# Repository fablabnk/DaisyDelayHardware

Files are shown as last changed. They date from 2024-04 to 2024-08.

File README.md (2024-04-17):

This repo documents the hardware design of a Daisy Seed-based Eurorack module called the Daisy Delay and contains the KiCad files for the project.

The Daisy Delay is planned as simple 6HP mono delay-line module, but can easily be used as a development platform for any kind of single-in/single-out audio processor.

This README gives an overview of the project, but there are also seperate notes for the [schematic](notes_schematic.md) and the [PCB](notes_pcb.md).

The module was first prototyped in VCVRack, before before being converted back to code that will run on the Seed. For more details on the VCVRack plugin, see [here](https://github.com/fablabnk/VaseProtoPlugin/tree/delay_line_params).

# Components / Bill of Materials (BOM)

The 

- 2 x 10K (for now) potentiometers
- 1 x SPST mini switch
- 1 x small LED (? diameter)
- 4 x Thonkiconn mono switching jack sockets (PJ301M-12)
- 1 x TL072 op amp
- 1 x TL074 op amp
- 1 x Shrouded 10 pin power connector
- various resistors
- various ceramic capacitors

# Workflow

Below is the basic workflow I am following to develop the module. 

1. Design schematic
- symbol and footprint for Seed Rev4 are already included in KiCad - search for "electrosmith"

2. Design front panel in Kicad PCB editor
- use VCV plugin panel .svg as template
- laser cut on paper / thin card first to test fit

3. Layout and Route PCB
- one board which drops onto components
- laser cut on paper / thin card first to test fit
- 2 layer / 4 layer routing?

4. Convert code to seed format
- test code on Pod

5. Send for fabrication (PCBWay)
- Order 5 x front and back panels

# Useful Links

https://github.com/clacktronics/Eurorack_KiCAD_templates

# Concerns / To Do

- Simpler hardware module first...probably!
- Symbol is only for Seed Rev 4 and we are now on Rev 7, but each Daisy Seed is pin to pin compatible with one another 
- Revisions were only to replace depricated audio codecs. See here: https://daisy.nyc3.cdn.digitaloceanspaces.com/products/seed/Daisy_Seed_datasheet.pdf

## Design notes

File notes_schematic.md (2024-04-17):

To put together the schematic for the Daisy Delay, I studied the schematics of the [Daisy Patch](https://daisy.nyc3.cdn.digitaloceanspaces.com/products/patch/ES_Daisy_Patch_Rev4.pdf) which contains most of what we need to know.

https://daisy.nyc3.cdn.digitaloceanspaces.com/products/patch-sm/ES_Daisy_Patch_SM_Schematic.pdf

# Switch and LED

The [datasheet PDF](https://daisy.nyc3.cdn.digitaloceanspaces.com/products/seed/Daisy_Seed_datasheet.pdf) has some

GPIO

`Pin Functions - Table 2`

# Eurorack 'conditioning'
There are three

1. ADC Inputs

2. Audio I/O
- attentuating a Eurorack level audio signal to line level on the way in
- boosts the line level signal to Eurorack level on the way out

3. Power
- deriving an isolated +5V from the Eurorack +-12V rails

# 1. ADC Inputs

For each of the two parameters in our Daisy Delay ('delay time' and 'feedback'), we need to:
    a. Sum the CV input voltage (coming in at the jack) with that of the potentiometer
    b. Scale the summed signal so that it falls within the range the Seed ADC pins expect (0-3.3V)

Here is the schematic for the circuit:

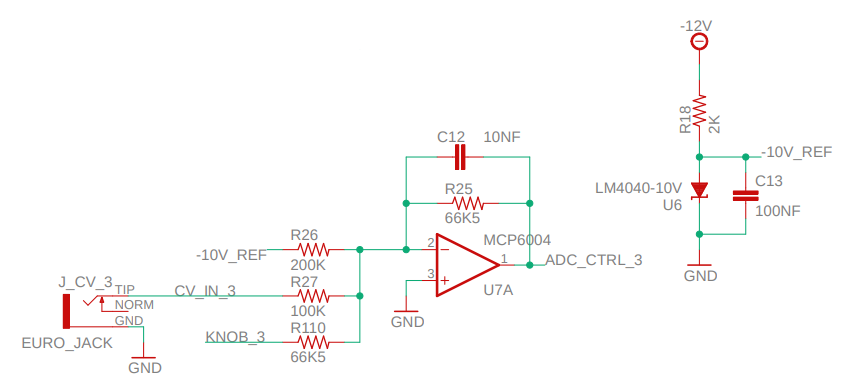
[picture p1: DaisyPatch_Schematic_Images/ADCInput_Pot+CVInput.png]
Pot + CV Input


## The Input Signals

Let's start with the CV input voltage (CV_IN_3). According to Eurorack standards this will fall within the +-5V range. It is followed by a 100K resistor.

Now let's consider the potentiometer (KNOB_3). We can see from another part of the schematic (below) that KNOB_3 is:
- a 10K potentimeter
- one side is connected to the `3.3V Analog` output pin of the Daisy Seed
- the other side is connected to ground
- the middle 'wiper' terminal comes into our circuit above

Connected in this way, the potentiometer creates a voltage divider circuit, where at one extreme of it's range, the output voltage on the wiper terminal will be close to 0V and at the other extreme it will be close to 3.3V. The chosen resistance value (in this case 10K) will affect the range, sensitivity, and resolution of the output voltage.

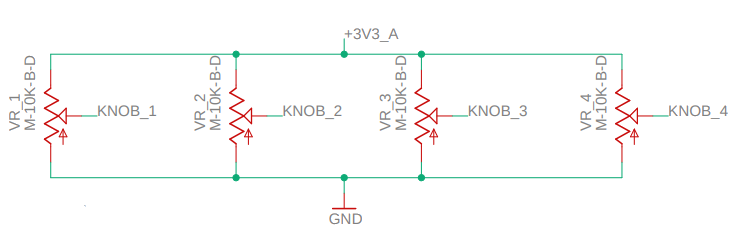
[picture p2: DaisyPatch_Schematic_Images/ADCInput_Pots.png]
Pots


So our KNOB_3 signal will fall within the 0-3.3V range. We can also see that it is followed by a 66.5K resistor.

Finally we have our -10V reference. On the right side of the first image above, we can see another schematic. This shows:
- our -12V coming in (from the Eurorack -12V rail)
- a 200K resistor placed in series with it
- then we [LM4040 Shunt Voltage Reference](https://www.ti.com/lit/ds/symlink/lm4040.pdf) whose purpose is to provide a stable and precise -10V output
- this is placed in parallel with a 100NF capacitor, to ensure a clean and stable output voltage under varying operating conditions
- both of which are connected to ground

Back on the left side, we can see that our -10V reference voltage is followed by a 200K resistor

## The Op Amp

We can see that our op amp is connected as follows:
- The negative input (known as the inverting input) is connected in parallel to a 10NF capacitor and a 66.5K resistor
    - These two components are also also both connected to the output of the op amp
    - This is also the output of our circuit (ADC_CTRL_3), which is connected to a Daisy Seed ADC Input pin
- The positive input (known as the non-inverting input) is connected to ground.

As we can see in the extra part of the schematic below, the op amp is powered by the same Daisy Seed pin that powers our potentiometers (the 3.3V Analog pin).

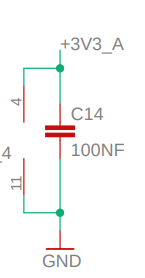
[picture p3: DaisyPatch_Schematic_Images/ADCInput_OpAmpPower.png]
Op Amp Power


This is an integrator circuit

`
The inverting amplifier can be extended by adding more input sockets (J1) and corresponding input resistors (R1). The right terminals of all input resistors are connected to the inverting input (-) of the operational amplifier O1. The relation between the corresponding input resistor R1 and R2 (the same for all inputs) defines the sensitivity of the input in question. If all resistors have the same value (e.g. 100 kOhm) the amplification is "1" for all inputs. Lowering R1 (e.g. 47k or 22k) increases the sensitivity of the input in question. Increasing R2 (e.g. 220k or 1M) increases the amplification resp. sensitivity for all inputs simultaneously.
`

weighted summing amplifier

[https://www.doepfer.de/DIY/a100_diy.htm]

Q: will the signal be "uninverted" in code 

We can note that:
-10V reference 200K
+-5V CV input 100K
0-3.3V potentiometer 66.5K
right side 66.5K

Q: what is the purpose of the -10V reference voltage? the -10V reference biases or shifts the level downwards

# 2. Audio I/O

Here we are using op amps again - in this case quad op amps in the form of the TL074. Let's begin this time by seeing how they are powered:

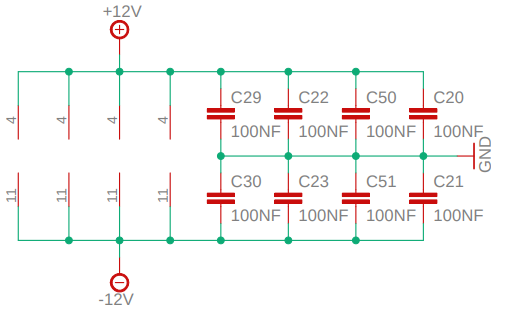
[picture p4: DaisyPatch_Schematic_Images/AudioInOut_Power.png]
Audio InOut Power


Here we can see that the op amp chips are powered directly from the eurorack +12V and -12V rails. For each quad op amp we use two 100NF capacitors to bridge across the + and - terminals to ground. This is to remove noise and/or smooth out any fluctuations in power.

Now let's look at our Audio In and Audio Out circuits next to each other:

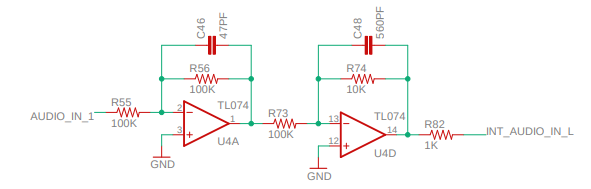
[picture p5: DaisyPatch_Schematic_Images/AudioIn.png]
Audio In

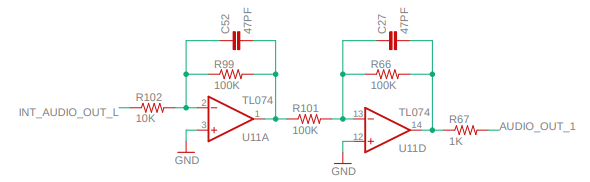
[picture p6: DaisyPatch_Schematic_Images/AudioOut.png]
Audio Out


Comparing them, we can see that:
- all the op amps are configured to operate as 'inverting' op amps i.e. the polarity between input and output is reversed
- both have a 1K resistor as the last element in the chain
- both have two op amp 'stages', including one with no amplification or attenution (100K resistor on left and right)
    - this is used to counteract the 'inverting' nature of the other op amp in the circuit
- the audio in circuit attenuates using the 2nd op amp (by having a 100K resistor on left, 10K resistor on right)
- the audio out circuit amplifies using the 1st op amp (by having a 10K resistor on left, 100K resistor on right)

Questions:
- Why always a 1K resistor at the end? Does the load have to be less?
- Why use inverting amplifiers at all?
- Why are TL074's used here with audio and MCP6004's when working with ADCs? They are both quad op amps. Answerish here: https://modwiggler.com/forum/viewtopic.php?t=193048

# 3. Power

We need +5V to power our Daisy Seed, the question is where it get it from? There are two options here:
1. Use the dedicated +5V rail (if we have it, most but not all power supplies do)
2. Derive our +5V from the +12V rail (e.g. with a regulator)

Commercial designs follow the second option to ensure ultimate compatability, but we don't have that concern (yet). The question is more, do all the power supplies we are likely to use have the +5V rail? The answer luckily is yes, in our case:
- the [TipTop µZeus](https://schneidersladen.de/de/tiptop-audio-uzeus-modul-mit-flying-bus-boards) does
- so too does our [USB Powerthingies](https://docs.google.com/document/d/1JAcD3iRaLf3Jpy0aVLl79c0GiPyVQEmC2FkkPij2Vjg/edit) by [Timo Rozendal](https://www.timorozendal.nl/)

Another aspect to take into account is that we need to use the larger 16-pin eurorack power connector when connecting our modules, which will take up more space on the PCB and will require a corresponding cable (do we have one?). Previously I have used the [eurocad](https://github.com/nebs/eurocad) library which contains a schematic component for a Eurorack 2x5 pin power header. Unfortunately, it did not contain one for the 2x8 pin version, so I decided to make my own, following the pinouts shown here:

Euro Power Connector Pinouts

To do this I used KiCad's symbol editor, found my EURO_PWR_2x5 symbol, right clicked it and chose `Derive from Existing Symbol`, then expanded the box size and copied in 6 more pins. In producing the symbol, I noticed two issues with the 

1. the pins for the EURO_PWR_2x5 did not correspond to the ones on the above diagram
    - for example pins 1 and 2 referenced the +12V rail not -12V!
    - this isn't an issue as long as I am shrouding the right way around in the footprint i.e.

Typically in Eurorack the we have a red stripe that represents the -12V rail and we use a shrouded connector to ensure the cable isn't inserted the wrong way around.

https://noiseengineering.us/blogs/loquelic-literitas-the-blog/how-to-plug-in-a-module

2. I also saw that all pins were marked 'power output' and have adapted my version to differentiate between 'power input' and 'power output' pins. My finished 16-pin connector symbol looks like this:

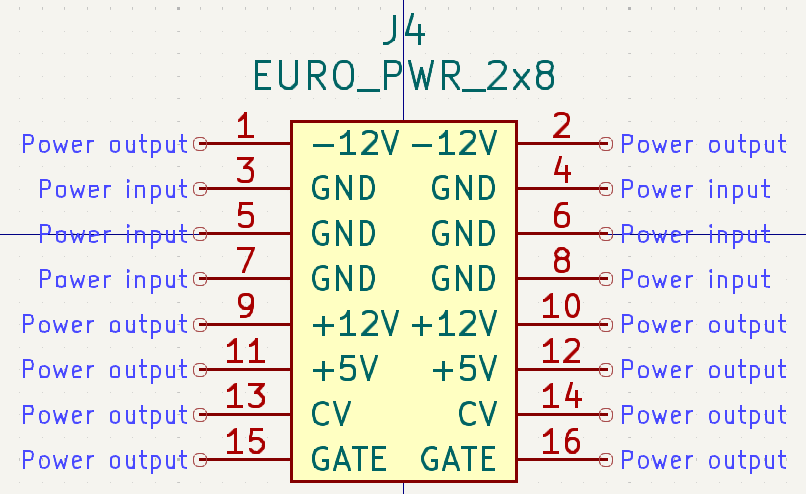
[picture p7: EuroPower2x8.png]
Euro Power 2x8 pin connector


## Deriving +5V from the +12v rail

If we did want to convert from +12V to +5V, we can look at how it was done in the Daisy Patch:

https://forum.kicad.info/t/please-explain-electrical-type-when-create-new-ic-pin/742/3

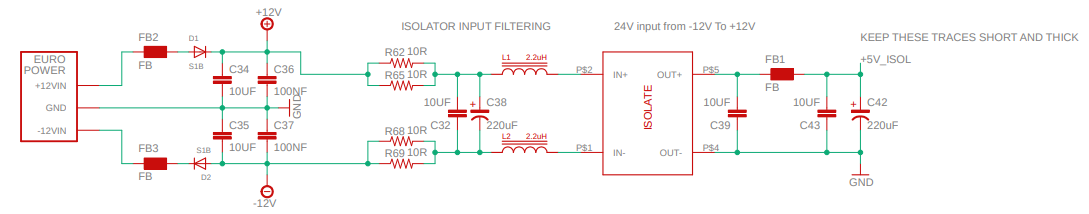
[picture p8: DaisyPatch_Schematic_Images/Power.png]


- The hoopy schematic symbols with two horizontal lines on top are iron core inductors
- The biggest point of confusion is the red 'isolate' box. What it is?

## Other power considerations

### Seed AGND to DGND

Note: For all applications, AGND must be connected to DGND!

### Capacitors

We can bridge capacitors from the power rails to ground, to help smooth out voltage fluctutions, maintain stability and eliminate interference. This is still a bit mysterious to me, but I did the following:

- For the +12V and -12V rails I placed 10uF and 100nF capacitors in parallel between the rail and ground, just as in the Daisy Patch power schematic above
- For the +5V rail I wasn't sure what is best practice, but again took from the above schematic after the 5V has been isolated, by placing 10uF (ceramic) and 220uF (electolytic) capacitors in parallel between the 5V rail and ground

### Ferrite beads

Supress high frequency noise
Should i use them?

# Things I learned along the way:

- how to protect the module from overvoltage and inserting the 10-pin cable the wrong way around (reverse polarity protection). Q: how is overvoltage handled actually?

- how to power the daisy seed using Eurorack +-12V by converting it to +-5V

- how small value capacitors are used between +12V and -12V and GND at each stage of our circuit to reduce noise e.g.
    - directly as the +-12V comes in from our Eurorack power supply
    - again when the +12V is used at the ADC Input stage
    - again when the +12V and +3.3V_A is used at our Audio In/Out stage
    - ???Why is a capacitor placed in parallel with resistor over input/output of op amp?

- how to convert from the signal levels Eurorack modules expect to ones that the Daisy Seed expects

- how to use an analog circuit sum the potentiometer value with the CV input value for each parameter

- which values potentiometers to use? i.e. does it matter if we use 10K, 50K, 100K?

# Elements of the Schematic

## Daisy Seed

The pins on the Daisy Seed we will need are as follows:

| Pin Name | Purpose |
| --- | --- |
| AUDIO_IN_L | Line-level audio input
| AUDIO_OUT_L  | Line-level audio output
| ADC_0 | Analog to Digital convertor pin for our 'Delay Time' potentiometer + CV Input
| ADC_1 | Analog to Digital convertor pin for our 'Feedback' potentiometer + CV Input
| ADC_2 | Analog to Digital convertor pin for our 'Delay Length Short/Long' switch
| DAC? | LED
| V_IN | Voltage input which we will feed with 5V (apparently 12V also okay but generate more heat)
| +3V3_A | 3.3V Analog power, feeding our potentiometers
| +3V3_D | Digital
| AGND | Analog ground
| DGND | Digital ground

Note: “D” for Digital GPIO or “A” for Analog I/O, depending on use case
Note: DGND and AGND must be connected to each other outside of the Seed.

Conveniently, a schematic symbol is already included in KiCad for the Daisy Seed Rev 4. We are now on Rev 7, but newer Daisy Seed revisions are pin to pin compatible with the old ones and were only made in order to replace unavailable audio codecs. See [here](https://daisy.nyc3.cdn.digitaloceanspaces.com/products/seed/Daisy_Seed_datasheet.pdf) for more details.

## Audio In/Out

We need to translate here from standard eurorack voltage levels (10V peak-to-peak) to line level (1-1.75Vpp) that the Daisy Seed audio input expects. We also need to do the opposite when the audio leaves the daisy seed. In practice we will use op amps to attenuate the signal coming in and boost it going out. Here we will use the same TL074 quad op amp chip as in the Daisy Seed, as each circuit requires two op amp stages (why?).

1. Audio In
- attentuates from Eurorack level to line level
- 100K resistor -> TL074 op amp 100K -> 100K resistor -> TL074 op amp 10K -> 1K resistor

2. Audio Out
- boosts from Eurorack level to line level
- 10K resistor -> TL074 op amp 100K -> 100K resistor -> TL074 op amp 100K -> 1K resistor

Note: I considered to share a 6 input op amp chip with our ADC Input section, but this cannot easily be done in practice as the former needs +-3.3V whilst this one needs +-12V

## Switch

- ADC is overkill here, GPIO makes more sense as our switch only has 0 (LOW) and 1 (HIGH) positions

- refer to the GPIO the example [here](https://electro-smith.github.io/libDaisy/md_doc_2md_2__a1___getting-_started-_g_p_i_o.html):

- use GPIO pin D0 (Daisy Seed pin 1)
- configured as an input
- configured use a pull up resistor
- my_button.Init(D0, GPIO::Mode::INPUT, GPIO::Pull::PULLUP);
- [Switch class](https://electro-smith.github.io/libDaisy/classdaisy_1_1_switch.html#ad14a8ae20033d940d6c9eeb03c138)void daisy::Switch::Init(dsy_gpio_pin pin,float update_rate, Type t, Polarity pol, Pull pu) 
- hardware: connect one side of the switch to the GPIO input, and other side to GND

## LED

- use GPIO pin D1 (Daisy Seed pin 2)
- configured as an output
- pull up/down is not relevant here
- We connect one side of our LED to the GPIO input and the other side to GND and use a pull up resistor?
- my_led.Init(D1, GPIO::Mode::OUTPUT);
- [LED class](https://electro-smith.github.io/libDaisy/classdaisy_1_1_led.html)void daisy::Led::Init(dsy_gpio_pin pin, bool invert, float samplerate = 1000.0f)	
- hardware: D0 -> resistor -> + LED - -> GND

Determine the forward voltage drop and current rating of the LED you intend to use. This information is crucial for selecting an appropriate resistor to limit the current through the LED. using  Ohm's Law.

## Power

The power circuit of the Daisy Seed details some 

1. We take +-12V from our Eurorack power supply using a 10-pin connector

2. For both the +12V and -12V rails, we insert separately:
    - a ferrite bead (to filter out very high frequency interference) [see here](https://modwiggler.com/forum/viewtopic.php?t=91515&start=10) apparently important for CPU-based module
    - an S1B diode (for reverse polarity protection). This not the only approach e.g. 1N4001 diodes

3. We bridge both rails to GND using 10uF and 100nF capacitors

- this is for noise reduction

4. We send out to our internal +-12V rails

5. Providing 5V to power the Seed

- we perform isolator input filtering
- we somehow drop the signal to 5V before sending to +5V_ISOL to power the seed (VIN)
- Q: What does the Isolate block do here?

Apparently another approach would be to step down using a LM7805 

# Which symbols and footprint to use for Thonkiconn jacks

symbol: Connector:AudioJack2_SwitchT
footprint: Connector_Audio:Jack_3.5mm_QingPu_WQP-PJ398SM_Vertical_CircularHoles

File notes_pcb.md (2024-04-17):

Q's?
- should LM4040 pin 3 be connected anywhere?
- what package should LM4040 have - what can we buy?
- what to do about switch - cut holes for it?
- panel layout
- don't forget thicker trace for power

# The process

- In schematic editor `Tools -> Edit Symbol Fields` helps to quickly and systematically assign footprints!
- Do we have a footprint for 2x8 Eurorack power connector? If not, make one!
    - closest generic is: Connector_PinHeader_2.54mm:PinHeader_2x08_P2.54mm_Vertical - using it for now
    - also could use the one from HagiwoMixer
- Need to order the following physical components
    - MCP6002
    - LM4040-10 - which package - SOT-23 or 

- LED diameter - 3mm/5mm? Note: Resistor value is dependent on desired brightness and/or LED part
- switch dimensions
- switch is not PCB mountable - what to do here? where to place on board, which footprint to use?
- breadboard the switch and LED as an example
- this time do a design rules check

# Multiple boards
The design will require two stacked PCBs

1. Mounting board
    - for pots, jacks etc
2. Seed board
    - for

- Components will be mounted onto the front side of board 1
- The panel will sit on top and be attached by thonkiconn screws
- On the rear side of board 1 there will be pin sockets to the left and right
- On the front side of board 2 there will be pin headers
- How many pins will be needed?
- On the rear side of board 2 there will left and right pin headers for the daisy seed to slot into
- There will also be the 16 pin power connector

It is suggested to place the pin sockets and headers on the schematic, but this makes the overall logic very unclear. Is there another way to do it?

https://forum.kicad.info/t/how-to-connect-modular-stacked-pcbs/16662/6

KiCad does not have real built-in support for panels yet.

A panel in PCB design refers to a larger substrate containing multiple individual PCBs arranged in a grid pattern for streamlined fabrication and assembly processes.

Each KiCad board file refers to a single PCB design. There is no official support for creating arrays or panels of PCBs within KiCad, although some community-created add-ons provide this functionality.

This thread offers a workflow
https://modwiggler.com/forum/viewtopic.php?t=184448

Just leave the connections between boards in the ratsnest, route everything else, then keep a manual checklist of how these go through the pin headers

Right now there looks like around 10 connections

How to offset the numbers on the right hand set of sockets/headers to avoid confusion?

- I could include the pin headers on the schematic with simple to/from labels, which wouldn't break the logic

# Panel Design

Layout will be like our VCVRack module here

- `Flip Board View` before

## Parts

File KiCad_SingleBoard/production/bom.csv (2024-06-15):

Designator | Footprint | Quantity | Value | LCSC Part #
C1, C11, C12, C15, C6 | C_Disc_D3.0mm_W1.6mm_P2.50mm | 5 | 103
C10, C13, C14, C16, C7, C8, C9 | C_Disc_D3.0mm_W1.6mm_P2.50mm | 7 | 104
C2, C4, C5 | C_Disc_D3.0mm_W1.6mm_P2.50mm | 3 | 470
C3 | C_Disc_D3.0mm_W1.6mm_P2.50mm | 1 | 561
D1 | LED_D5.0mm | 1 | LED
J1 | PJ301M-12_T_S | 1 | AUDIO OUT
J2 | PJ301M-12_T_S | 1 | FBK CV IN
J3 | PJ301M-12_T_S | 1 | DELAY CV IN
J5 | PJ301M-12_T_S | 1 | AUDIO IN
J6 | Pins_2x08_2.54mm_TH_EuroPower_Shrouded | 1 | Eurorack_Power_16pin_Shrouded
R1, R15 | R_Axial_DIN0207_L6.3mm_D2.5mm_P7.62mm_Horizontal | 2 | 200K
R10, R9 | R_Axial_DIN0207_L6.3mm_D2.5mm_P7.62mm_Horizontal | 2 | 10K
R11, R12, R13, R16, R2, R5, R6, R8 | R_Axial_DIN0207_L6.3mm_D2.5mm_P7.62mm_Horizontal | 8 | 100K
R14, R20, R7 | R_Axial_DIN0207_L6.3mm_D2.5mm_P7.62mm_Horizontal | 3 | 1K
R17, R18, R3, R4 | R_Axial_DIN0207_L6.3mm_D2.5mm_P7.62mm_Horizontal | 4 | 66.5K
R19 | R_Axial_DIN0207_L6.3mm_D2.5mm_P7.62mm_Horizontal | 1 | 2K
RV1 | Pot_9mm_DShaft | 1 | DELAY 10K
RV2 | Pot_9mm_DShaft | 1 | FBK 10K
SEED1 | Electrosmith_Daisy_Seed | 1 | Electrosmith_Daisy_Seed_Rev4
SWITCH | SW_Slide-03_Wuerth-WS-SLTV_10x2.5x6.4_P2.54mm-SolderLugs | 1 | SW_SPDT
U1 | SOT-23 | 1 | LM4040
U2 | DIP-14_W7.62mm | 1 | TL074
U3 | DIP-8_W7.62mm | 1 | MCP6002

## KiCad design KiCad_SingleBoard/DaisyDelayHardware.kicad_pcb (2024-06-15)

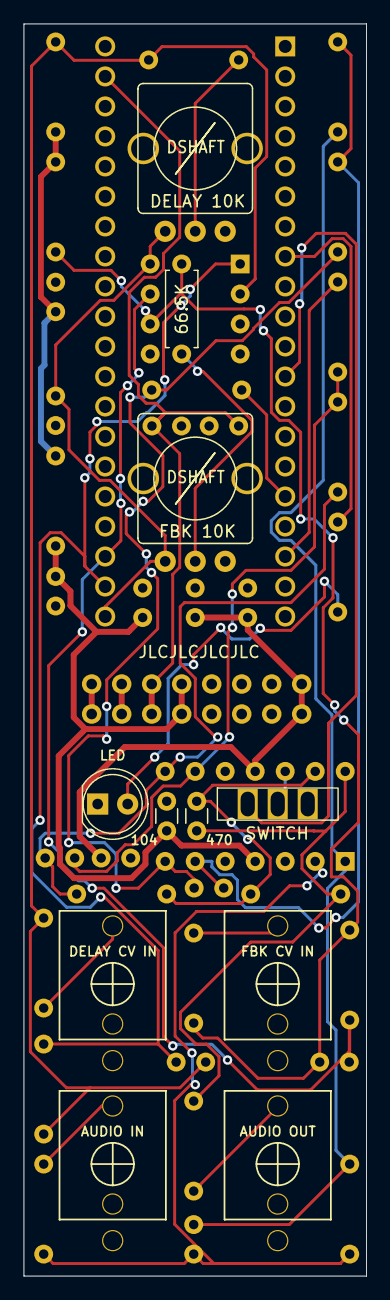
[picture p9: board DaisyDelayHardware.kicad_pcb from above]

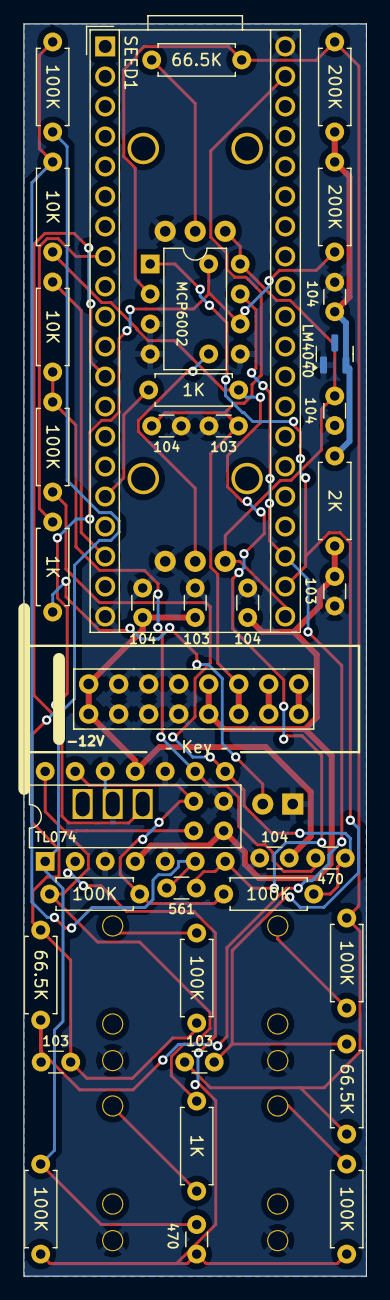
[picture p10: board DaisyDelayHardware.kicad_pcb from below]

Board: 2 copper layers, 29.0 x 106.0 mm, 49 parts (38 on the bottom side), 31 nets.

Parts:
C1, C6, C11, C12, C15: 103; C_Disc_D3.0mm_W1.6mm_P2.50mm
C2, C4, C5: 470; C_Disc_D3.0mm_W1.6mm_P2.50mm
C3: 561; C_Disc_D3.0mm_W1.6mm_P2.50mm
C7, C8, C9, C10, C13, C14, C16: 104; C_Disc_D3.0mm_W1.6mm_P2.50mm
D1: LED; LED_D5.0mm
J1: AUDIO OUT; PJ301M-12_T_S
J2: FBK CV IN; PJ301M-12_T_S
J3: DELAY CV IN; PJ301M-12_T_S
J5: AUDIO IN; PJ301M-12_T_S
J6: Eurorack_Power_16pin_Shrouded; Pins_2x08_2.54mm_TH_EuroPower_Shrouded
R1, R15: 200K; R_Axial_DIN0207_L6.3mm_D2.5mm_P7.62mm_Horizontal
R2, R5, R6, R8, R11, R12, R13, R16: 100K; R_Axial_DIN0207_L6.3mm_D2.5mm_P7.62mm_Horizontal
R3, R4, R17, R18: 66.5K; R_Axial_DIN0207_L6.3mm_D2.5mm_P7.62mm_Horizontal
R7, R14, R20: 1K; R_Axial_DIN0207_L6.3mm_D2.5mm_P7.62mm_Horizontal
R9, R10: 10K; R_Axial_DIN0207_L6.3mm_D2.5mm_P7.62mm_Horizontal
R19: 2K; R_Axial_DIN0207_L6.3mm_D2.5mm_P7.62mm_Horizontal
RV1: DELAY 10K; Pot_9mm_DShaft
RV2: FBK 10K; Pot_9mm_DShaft
SEED1: Electrosmith_Daisy_Seed_Rev4; Electrosmith_Daisy_Seed
SWITCH: SW_SPDT; SW_Slide-03_Wuerth-WS-SLTV_10x2.5x6.4_P2.54mm-SolderLugs
U1: LM4040; SOT-23
U2: TL074; DIP-14_W7.62mm
U3: MCP6002; DIP-8_W7.62mm

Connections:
+3V3: C8.1, RV1.1, RV2.1, SEED1.21 (3V3_A), U3.8 (V+)
+5V: C15.1, C16.1, J6.5 (+12V), J6.6, SEED1.39 (VIN)
+12V: C10.1, C12.2, C13.2, J6.7 (12V), J6.8 (+12V), R19.1, U2.4 (V+)
-10V: C7.1, R1.1, R15.1, R19.2, U1.2 (A)
-12V: C9.2, C11.1, C14.1, J6.15 (-12V), J6.16, U2.11 (V-)
ADC_IN_0: C1.2, R4.2, SEED1.22 (ADC_0), U3.1
ADC_IN_1: C6.2, R18.2, SEED1.23 (ADC_1), U3.7
AUDIO_IN_L: R7.2, SEED1.16 (AUDIO_IN_1)
AUDIO_OUT_L: R10.1, SEED1.18 (AUDIO_OUT_1)
GND: C7.2, C8.2, C9.1, C10.2, C11.2, C12.1, C13.1, C14.2, C15.2, C16.2, D1.1 (K), J1.S, J2.S, J3.S, J5.S, J6.9 (GND), J6.10 (GND), J6.11 (GND), J6.12 (GND), J6.13 (-12), J6.14 (-12V), RV1.3, RV2.3, SEED1.20 (AGND), SEED1.40 (DGND), SWITCH.1 (A), U1.1 (K), U2.3 (+), U2.5 (+), U2.10 (+), U2.12 (+), U3.3 (+), U3.4 (V-), U3.5 (+)
LED_OUT: R20.1, SEED1.8 (SPI1_CS)
unnamed: C2.2, R6.1, R8.2, U2.1
unnamed: C3.2, R7.1, R9.2, U2.7
unnamed: C4.2, R11.2, R12.1, U2.8
unnamed: C5.2, R13.2, R14.1, U2.14
unnamed: D1.2 (A), R20.2
unnamed: J1.T, R14.2
unnamed: J2.T, R16.1
unnamed: J3.T, R2.1
unnamed: J5.T, R5.1
unnamed: J6.1, J6.2
unnamed: J6.3, J6.4
unnamed: R3.1, RV1.2
unnamed: R17.1, RV2.2
unnamed: C2.1, R5.2, R8.1, U2.2 (-)
unnamed: C3.1, R6.2, R9.1, U2.6 (-)
unnamed: C4.1, R10.2, R11.1, U2.9 (-)
unnamed: C5.1, R12.2, R13.1, U2.13 (-)
unnamed: C1.1, R1.2, R2.2, R3.2, R4.1, U3.2 (-)
unnamed: C6.1, R15.2, R16.2, R17.2, R18.1, U3.6 (-)
SWITCH_IN: SEED1.12 (I2C1_SCL), SWITCH.2 (B)

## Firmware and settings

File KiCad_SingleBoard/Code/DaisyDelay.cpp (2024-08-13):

#include "daisysp.h"
#include "daisy_seed.h"
// #include <led.h>

// Interleaved audio definitions
#define LEFT (i)
#define RIGHT (i + 1)

// Set max delay time to 0.75 of samplerate.
#define MAX_DELAY static_cast<size_t>(48000 * 0.75f)

using namespace daisysp;
using namespace daisy;

static DaisySeed hw;

// Declare a DelayLine of MAX_DELAY number of floats.
static DelayLine<float, MAX_DELAY> del;

static void AudioCallback(AudioHandle::InterleavingInputBuffer  in,
                          AudioHandle::InterleavingOutputBuffer out,
                          size_t                                size)
{
    float osc_out, env_out, feedback, del_out, sig_out;
    for(size_t i = 0; i < size; i += 2)
    {
        // Parameter 1: Delay Time (secs)
		float delayTimeParam = hw.adc.GetFloat(0);
		// float clampedDelayTimeParam = clamp(delayTimeParam, 0.f, 1.f);

		// Choose min and max delay times based on position of switch
        switch.Debounce();

		if (switch.Pressed())
		{
			led.Set(1.0f);
			minDelayTimeSecs = MIN_SHORT_DELAY_TIME;
			maxDelayTimeSecs = MAX_SHORT_DELAY_TIME;
		}
		else
		{
			led.Set(0.0f));
			minDelayTimeSecs = MIN_LONG_DELAY_TIME;
			maxDelayTimeSecs = MAX_LONG_DELAY_TIME;
		}
		
		float rangeDelayTimeSecs = maxDelayTimeSecs - minDelayTimeSecs;
		float delayTime = (clampedDelayTimeParam * rangeDelayTimeSecs) + minDelayTimeSecs;

        // smoothing quick changes between delay times
		float smoothedDelayTime;
		float coeff = 1.0f / (2.5f * args.sampleRate);
		daisysp::fonepole(smoothedDelayTime, delayTime, coeff);
		
		del.SetDelay(args.sampleRate * delayTime);

        del_out = del.Read();
        sig_out  = del_out + in[LEFT];

		// Parameter 2: Feedback
		float feedbackParam = hw.adc.GetFloat(1);
		// float clampedFeedbackParam = clamp(feedbackParam, 0.f, 1.f);
        feedback = (del_out * feedbackParam * MAX_FEEDBACK) + in[LEFT];
        del.Write(feedback);

		outputs[LEFT] = sig_out;
    }
}

int main(void)
{
    // initialize seed hardware and daisysp modules
    float sample_rate;
    hw.Configure();
    hw.Init();

    AdcChannelConfig adcConfig;
    adcConfig.InitSingle(hw.GetPin(22));
    adcConfig.InitSingle(hw.GetPin(23));

    Switch switchy;
    switchy.Init(hw.GetPin(12), 1000);

    Led led;
    led.Init(8, 1000);

    hw.adc.Init(&adcConfig, 1);
    hw.adc.Start();

    hw.SetAudioBlockSize(4);
    sample_rate = hw.AudioSampleRate();
    del.Init();

    // Set Delay time to 0.75 seconds
    del.SetDelay(sample_rate * 0.75f);

    // start callback
    hw.StartAudio(AudioCallback);

    while(1) {}
}

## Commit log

2024-04-17 routed first pcb
    [DaisyDelayHardware.kicad_pcb, DaisyDelayHardware.kicad_sch, DaisyDelayHardwareTestRoute.kicad_pcb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]
2024-06-08 added single board version of project - half-routed
    [DaisyDelayHardware.kicad_pcb, DaisyDelayHardware.kicad_sch]
2024-06-13 backup before pcb revision
    [DaisyDelayHardware.kicad_pcb, DaisyDelayHardware.kicad_sch, DaisyDelayHardware_Panel.kicad_pcb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]
2024-06-15 pcb revised - but doesn't meet jlcpcb design rules
    [DaisyDelayHardware.kicad_pcb, DaisyDelayHardware.kicad_sch, bom.csv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]
2024-06-15 DRC now adheres to custom design rules for jlcpcb
    [DaisyDelayHardware.kicad_pcb, bom.csv, designators.csv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]
2024-08-13 latest updates
    [DaisyDelayHardware.kicad_sch, DaisyDelayHardware_Panel_Basic.kicad_pcb, bom.csv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]
